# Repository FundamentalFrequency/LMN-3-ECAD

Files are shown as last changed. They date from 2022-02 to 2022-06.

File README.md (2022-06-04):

# LMN-3-ECAD

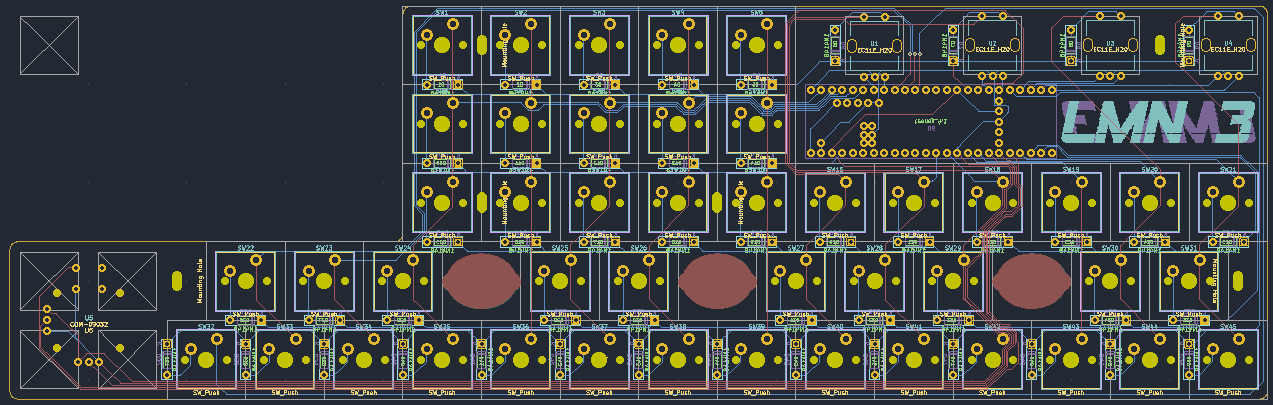
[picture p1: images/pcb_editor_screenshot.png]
screenshot of PCB

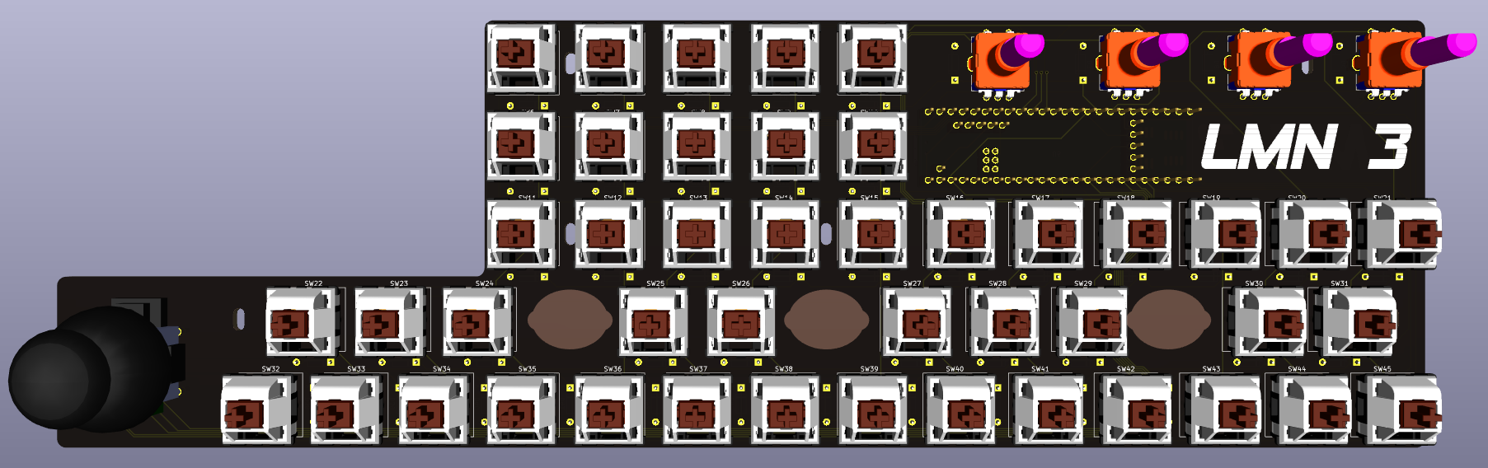
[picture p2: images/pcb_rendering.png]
screenshot of PCB Rendering


This repository contains the [KiCad 6](https://www.kicad.org/) project files for the LMN-3 PCB.

If you would like to support the project, please consider becoming a [sponsor](https://github.com/sponsors/stonepreston).

## Bill of Materials
| Description | Model | Quantity | URL |
|---|---|---|---|
| Diode | 1N4148 | 49 | https://www.amazon.com/McIgIcM-1n4148-switching-Standard-Through/dp/B06XB1R2NK |
| Rotary Encoder | EC11 | 4 | https://www.amazon.com/WayinTop-Encoder-Potentiometer-Electronics-Projects/dp/B08728K3YB?psc=1 |
| Switch | 5 pin mechanical keyboard switch | 45 | |
| Joystick | COM-09032 | 1 | https://www.sparkfun.com/products/9032 | |
| Microcontroller | Teensy 4.1 | 1 | https://www.pjrc.com/store/teensy41.html |
| Arduino Header Strip | | 2 | https://www.amazon.com/gp/product/B07PKKY8BX?psc=1 |

## Gerbers
Gerber files are available [here](https://github.com/FundamentalFrequency/LMN-3-ECAD/releases) if you would like to have a board house manufacture the PCB. 

## Thanks
This project would not be possible without the following free and open source projects:
- [KiCad](https://www.kicad.org/)
- [Keyswitch Kicad Library](https://github.com/perigoso/keyswitch-kicad-library)

### Sources for Footprints, Symbols, 3-D Models, and Other Resources
#### Encoders (Alps EC11E09244AQ)
- [Product Page](https://www.mouser.com/ProductDetail/Alps-Alpine/EC11E09244AQ?qs=fMKjfF2mFohVUA4%2Ftyw7NQ%3D%3D)
- [Datasheet and Mechanical Drawing](https://tech.alpsalpine.com/prod/e/html/encoder/incremental/ec11/ec11e09244aq.html)
- [3-D Model](https://www.snapeda.com/parts/EC11E09244AQ/ALPS/view-part/?welcome=home&t=EC11E)

#### Teensy 4.1
- [Product Page](https://www.pjrc.com/store/teensy41.html)
- [3-D Model](https://www.snapeda.com/parts/DEV-16771/SparkFun%20Electronics/view-part/?t=teensy)

#### Thumbstick (SparkFun COM-09032)
- [Product Page](https://www.digikey.com/en/products/detail/sparkfun-electronics/COM-09032/6823623)
- [Datasheet](https://media.digikey.com/pdf/Data%20Sheets/Sparkfun%20PDFs/COM-09032_Web.pdf)
- [3-D Model](https://www.snapeda.com/parts/COM-09032/SparkFun%20Electronics/view-part/?t=joystick)
- [Eagle Library](https://github.com/sparkfun/SparkFun-Eagle-Libraries)

#### Keyboard Switches (Keyswitch Kicad Library)
- [Footprints, Symbols, and 3-D Models](https://github.com/perigoso/keyswitch-kicad-library)

## License
Licensed under the  [CC-by-SA 4.0](https://creativecommons.org/licenses/by-sa/4.0/) license.

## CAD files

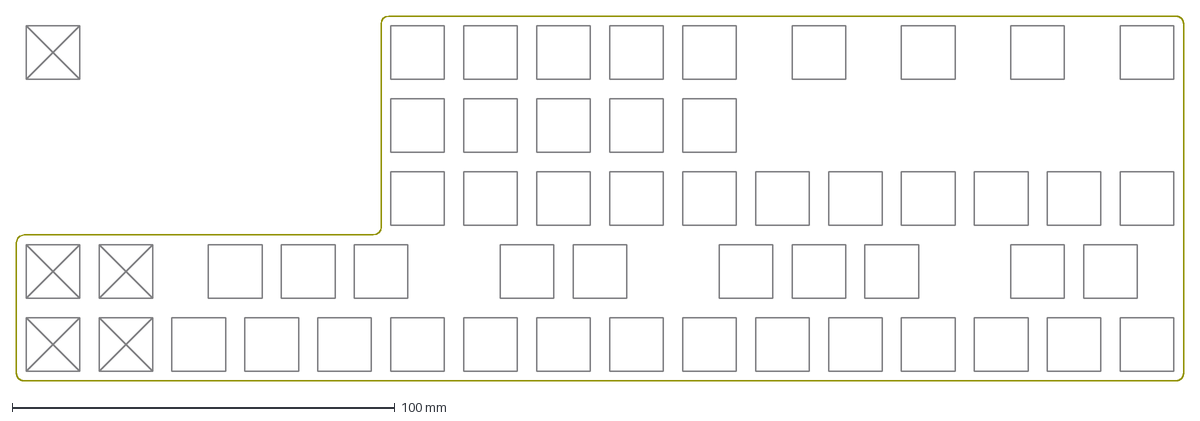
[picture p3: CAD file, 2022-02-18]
graphics/edge_cuts_and_user_drawings.dxf
304.8 x 95.2 mm

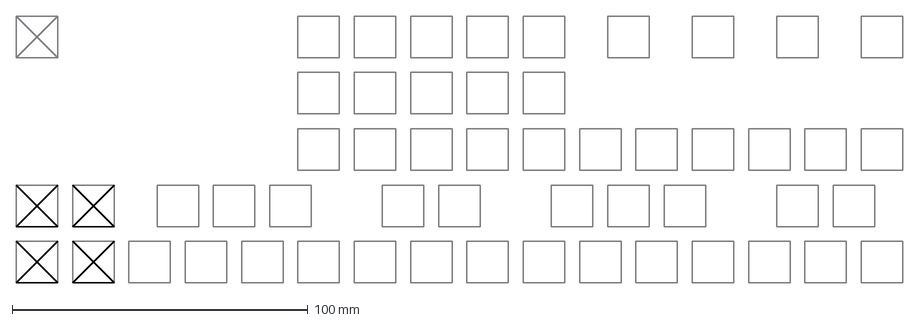
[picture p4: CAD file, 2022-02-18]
graphics/user_drawings.dxf
299.7 x 90.2 mm

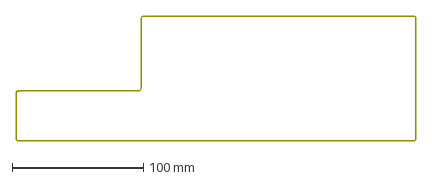
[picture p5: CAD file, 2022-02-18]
graphics/edge_cuts.dxf
304.8 x 95.2 mm

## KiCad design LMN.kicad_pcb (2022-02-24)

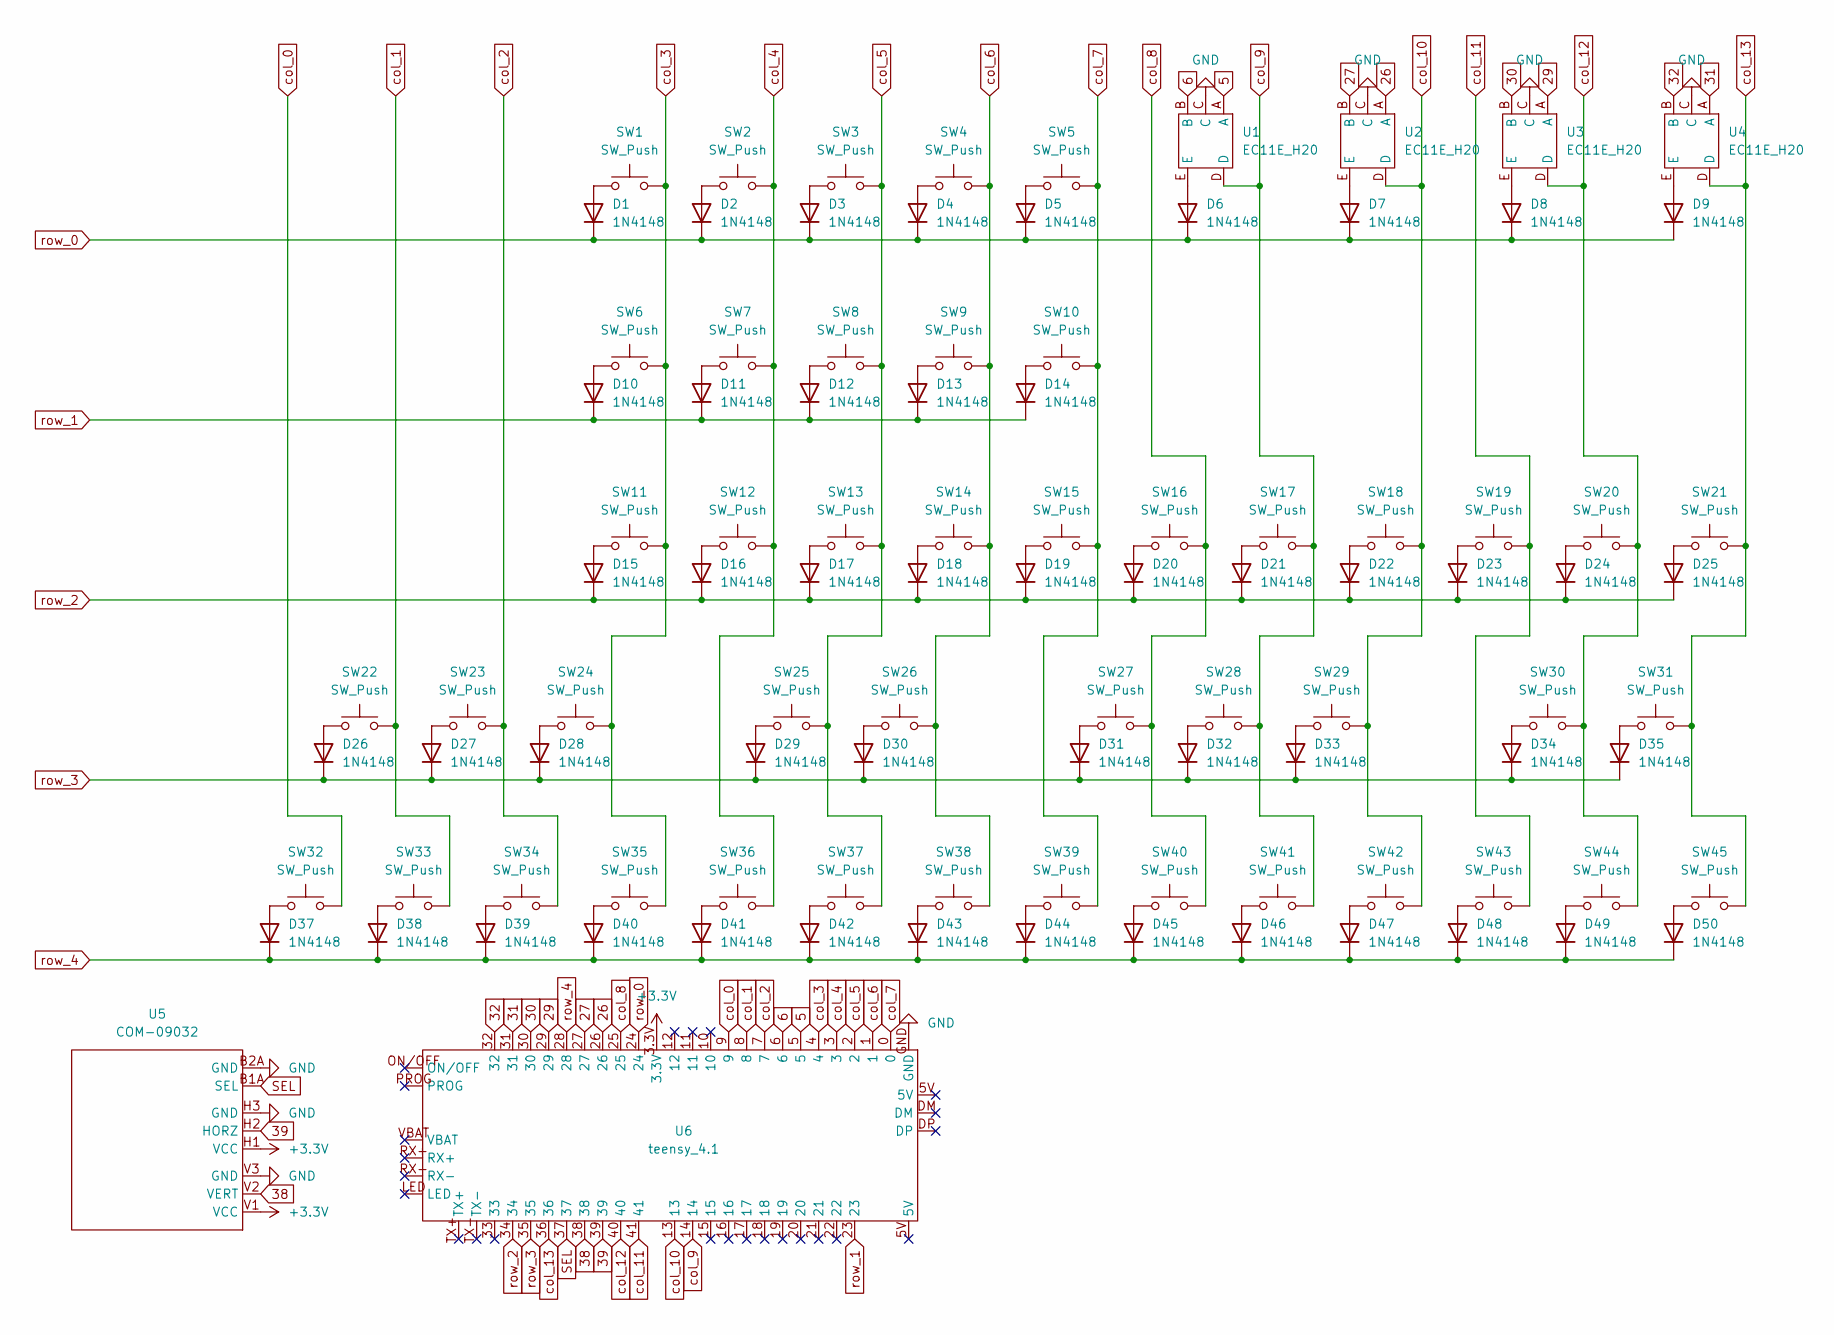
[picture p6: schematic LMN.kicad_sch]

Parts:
D1, D2, D3, D4, D5, D6, D7, D8, D9, D10, D11, D12, D13, D14, D15, D16, D17, D18, D19, D20, D21, D22, D23, D24, D25, D26, D27, D28, D29, D30, D31, D32, D33, D34, D35, D37, D38, D39, D40, D41, D42, D43, D44, D45, D46, D47, D48, D49, D50: 1N4148; D_DO-35_SOD27_P7.62mm_Horizontal
SW1, SW2, SW3, SW4, SW5, SW6, SW7, SW8, SW9, SW10, SW11, SW12, SW13, SW14, SW15, SW16, SW17, SW18, SW19, SW20, SW21, SW22, SW23, SW24, SW25, SW26, SW27, SW28, SW29, SW30, SW31, SW32, SW33, SW34, SW35, SW36, SW37, SW38, SW39, SW40, SW41, SW42, SW43, SW44, SW45: SW_Push; SW_Cherry_MX_PCB_1.00u
U1, U2, U3, U4: EC11E_H20
U5: COM-09032
U6: teensy_4.1

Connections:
5: U1.A, U6.5
6: U1.B, U6.6
26: U2.A, U6.26
27: U2.B, U6.27
29: U3.A, U6.29
30: U3.B, U6.30
31: U4.A, U6.31
32: U4.B, U6.32
38: U5.V2 (VERT), U6.38
39: U5.H2 (HORZ), U6.39
+3V3: U5.H1 (VCC), U5.V1 (VCC), U6.3.3V
GND: U1.C, U2.C, U3.C, U4.C, U5.B2A (GND), U5.H3 (GND), U5.V3 (GND), U6.GND
unnamed: D1.2 (A), SW1.1
unnamed: D2.2 (A), SW2.1
unnamed: D3.2 (A), SW3.1
unnamed: D4.2 (A), SW4.1
unnamed: D5.2 (A), SW5.1
unnamed: D6.2 (A), U1.E
unnamed: D7.2 (A), U2.E
unnamed: D8.2 (A), U3.E
unnamed: D9.2 (A), U4.E
unnamed: D10.2 (A), SW6.1
unnamed: D11.2 (A), SW7.1
unnamed: D12.2 (A), SW8.1
unnamed: D13.2 (A), SW9.1
unnamed: D14.2 (A), SW10.1
unnamed: D15.2 (A), SW11.1
unnamed: D16.2 (A), SW12.1
unnamed: D17.2 (A), SW13.1
unnamed: D18.2 (A), SW14.1
unnamed: D19.2 (A), SW15.1
unnamed: D20.2 (A), SW16.1
unnamed: D21.2 (A), SW17.1
unnamed: D22.2 (A), SW18.1
unnamed: D23.2 (A), SW19.1
unnamed: D24.2 (A), SW20.1
unnamed: D25.2 (A), SW21.1
unnamed: D26.2 (A), SW22.1
unnamed: D27.2 (A), SW23.1
unnamed: D28.2 (A), SW24.1
unnamed: D29.2 (A), SW25.1
unnamed: D30.2 (A), SW26.1
unnamed: D31.2 (A), SW27.1
unnamed: D32.2 (A), SW28.1
unnamed: D33.2 (A), SW29.1
unnamed: D34.2 (A), SW30.1
unnamed: D35.2 (A), SW31.1
unnamed: D37.2 (A), SW32.1
unnamed: D38.2 (A), SW33.1
unnamed: D39.2 (A), SW34.1
unnamed: D40.2 (A), SW35.1
unnamed: D41.2 (A), SW36.1
unnamed: D42.2 (A), SW37.1
unnamed: D43.2 (A), SW38.1
unnamed: D44.2 (A), SW39.1
unnamed: D45.2 (A), SW40.1
unnamed: D46.2 (A), SW41.1
unnamed: D47.2 (A), SW42.1
unnamed: D48.2 (A), SW43.1
unnamed: D49.2 (A), SW44.1
unnamed: D50.2 (A), SW45.1
SEL: U5.B1A (SEL), U6.37
col_0: SW32.2, U6.9
col_1: SW22.2, SW33.2, U6.8
col_2: SW23.2, SW34.2, U6.7
col_3: SW1.2, SW6.2, SW11.2, SW24.2, SW35.2, U6.4
col_4: SW2.2, SW7.2, SW12.2, SW36.2, U6.3
col_5: SW3.2, SW8.2, SW13.2, SW25.2, SW37.2, U6.2
col_6: SW4.2, SW9.2, SW14.2, SW26.2, SW38.2, U6.1
col_7: SW5.2, SW10.2, SW15.2, SW39.2, U6.0
col_8: SW16.2, SW27.2, SW40.2, U6.25
col_9: SW17.2, SW28.2, SW41.2, U1.D, U6.14
col_10: SW18.2, SW29.2, SW42.2, U2.D, U6.13
col_11: SW19.2, SW43.2, U6.41
col_12: SW20.2, SW30.2, SW44.2, U3.D, U6.40
col_13: SW21.2, SW31.2, SW45.2, U4.D, U6.36
row_0: D1.1 (K), D2.1 (K), D3.1 (K), D4.1 (K), D5.1 (K), D6.1 (K), D7.1 (K), D8.1 (K), D9.1 (K), U6.24
row_1: D10.1 (K), D11.1 (K), D12.1 (K), D13.1 (K), D14.1 (K), U6.23
row_2: D15.1 (K), D16.1 (K), D17.1 (K), D18.1 (K), D19.1 (K), D20.1 (K), D21.1 (K), D22.1 (K), D23.1 (K), D24.1 (K), D25.1 (K), U6.34
row_3: D26.1 (K), D27.1 (K), D28.1 (K), D29.1 (K), D30.1 (K), D31.1 (K), D32.1 (K), D33.1 (K), D34.1 (K), D35.1 (K), U6.35
row_4: D37.1 (K), D38.1 (K), D39.1 (K), D40.1 (K), D41.1 (K), D42.1 (K), D43.1 (K), D44.1 (K), D45.1 (K), D46.1 (K), D47.1 (K), D48.1 (K), D49.1 (K), D50.1 (K), U6.28

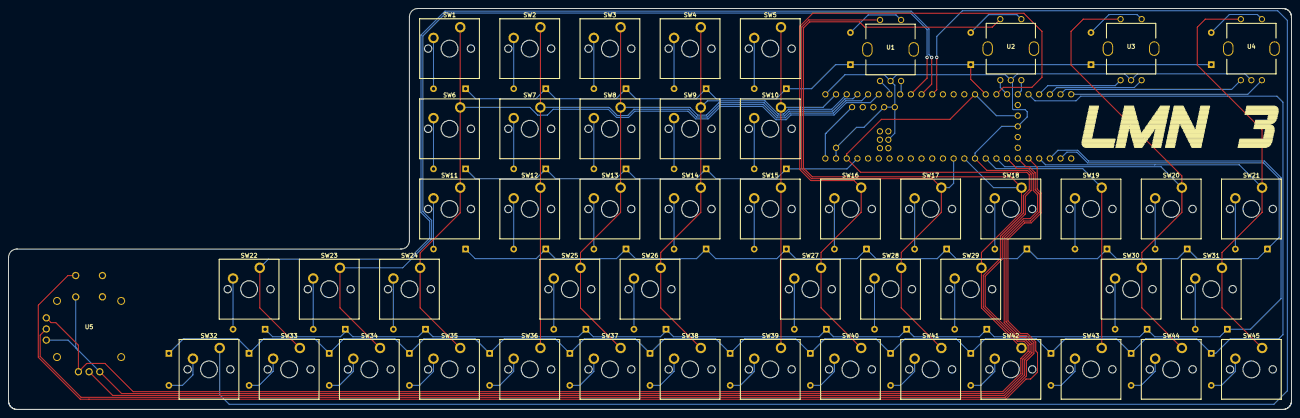
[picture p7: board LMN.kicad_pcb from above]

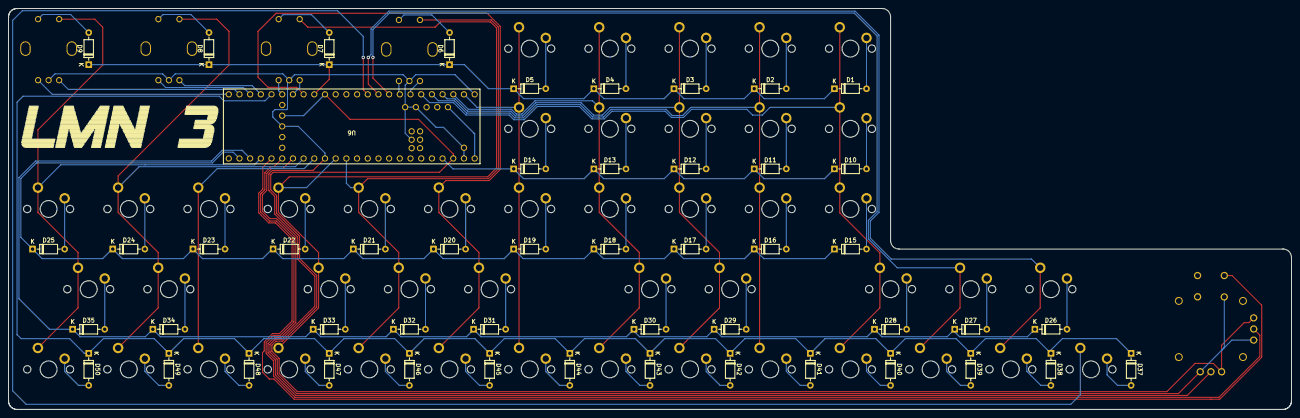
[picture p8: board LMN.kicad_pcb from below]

Board: 2 copper layers, 304.8 x 95.2 mm, 100 parts (50 on the bottom side), 81 nets.

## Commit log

2022-02-22 Change logos and other graphics
    [LMN-B_Cu.gbr, LMN-B_Mask.gbr, LMN-B_Paste.gbr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]
2022-02-23 Add mounting holes
    [LMN-B_Cu.gbr, LMN-B_Mask.gbr, LMN-B_Paste.gbr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]
2022-02-24 Update gerbers, fix incorrect footprint in switch
    [LMN-B_Cu.gbr, LMN-B_Mask.gbr, LMN-B_Paste.gbr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]
2022-02-24 Update gerbers
    [LMN-B_Cu.gbr, LMN-B_Mask.gbr, LMN-B_Paste.gbr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]
2022-05-13 Remove gerbers from source
    [LMN-B_Cu.gbr, LMN-B_Mask.gbr, LMN-B_Paste.gbr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]
